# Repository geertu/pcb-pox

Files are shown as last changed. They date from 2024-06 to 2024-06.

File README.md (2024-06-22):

# POX - Power-Opto Extension Board (KiCad PCB)

This is a small extension board to control operation of two development boards,
e.g. on your desk, or in a board farm.  It is mainly intended for use with
BCU/2 (https://github.com/geertu/pcb-bcu2), but it can be used with any
microcontroller or single-board computer that has a compatible I2C interface.

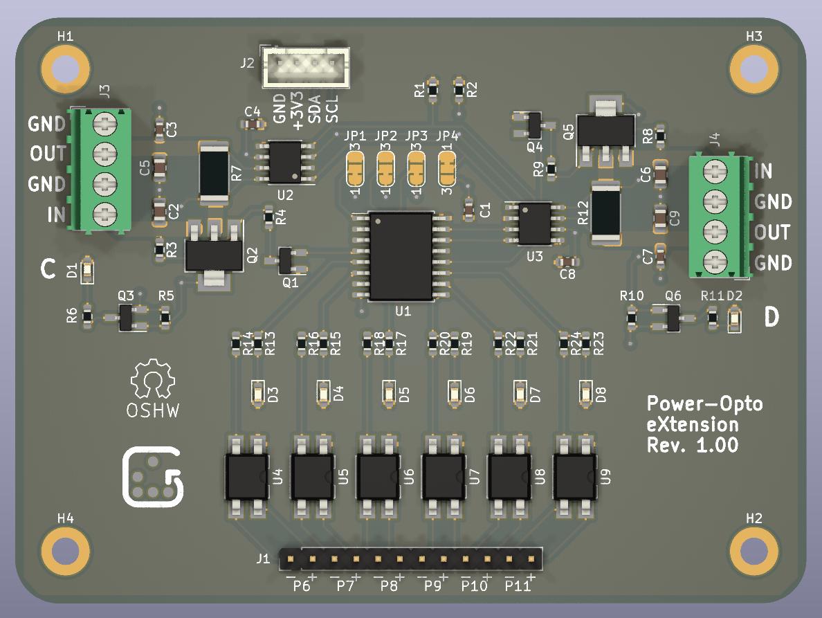
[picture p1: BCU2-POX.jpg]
PCB


## Features

  - Controlled over I2C,
  - Two power control and measurement channels (3.3-14V, max. 3.2A),
  - Six opto-isolators for e.g. reset, wake-up, and keypress simulation.

## Software

Software to run on BCU/2+POX is available from
https://github.com/geertu/teensy3-bcu2/tree/bcu2%2Bpox in source form.

## License

CC-BY-SA-4.0 (https://creativecommons.org/licenses/by-sa/4.0/)

## PCB and Parts

PCB and parts can be ordered at
https://aisler.net/geert/power-opto-extension/bcu2-pox (Disclaimer: I'm not
affiliated to AISLER). Note that the project at Aisler predates the change from
NTF6P02 to DMP6023LE-13.

## Bill Of Materials

  - C1, C3, C4, C7, C8: Capacitor, 100nF, SMD 0603/1608
  - C2, C5, C6, C9: Capacitor, 10µF, SMD 0805/2012, 25V
  - D1, D2: LED Green clear, SMD 0603/1608
  - D3-D8: LED Yellow clear, SMD 0603/1608
  - J1: Male 1x12 header 2.54mm
  - J2: Male 1x4 header, RM 2mm, e.g. JST B4B-PH-K
  - J3, J4: Screw type, terminal block, RM 3.5mm
  - Q1, Q3, Q4, Q6: MOSFET N-channel 60V 115mA, SOT23-3
  - Q2, Q5: MOSFET P-channel e.g. 60V 7A (DMP6023LE-13) or
				  20V 10A (NTF6P02), SOT223
  - R1, R2: Resistor, 4.7kΩ, SMD 0603/1608 (optional, I2C pull-ups)
  - R3, R8: Resistor, 47kΩ, SMD 0603/1608
  - R4, R9: Resistor, 10kΩ (when using DMP6023LE-13) or
		      47kΩ (when using NTF6P02), SMD 0603/1608
  - R5, R10: Resistor, 100kΩ, SMD 0603/1608
  - R6, R11, R13, R15, R17, R19, R21, R23: Resistor, 1kΩ, SMD 0603/1608
  - R7, R12: Resistor, 100mΩ, SMD 2512/6432, 1%, 2W
  - R14, R16, R18, R20, R22, R24: Resistor, 270Ω, SMD 0603/1608
  - U1: PFC8574, 16-SOIC (wide)
  - U2, U3: INA219xID power monitor, 8-SOIC
  - U4-U9: Opto-isolator, Mini-Flat-4, e.g. Broadcom HCPL-181-00CE

## Connector pinouts

  - J1: Opto-isolator channels 6-11

    Pin               | Function
    ----------------- | --------
     1-11 (odd pins)  | Emitter ("negative output")
     2-12 (even pins) | Collector ("positive output")

  - J2: I2C[A]

    Pin | Function
    --- | --------
     1  | GND
     2  | +3.3V
     3  | SDA
     4  | SCL

  - J3 / J4: Power channels C & D

    Pin | Function
    --- | --------
     1  | GND
     2  | Power OUT
     3  | GND
     4  | Power IN (3.3-14V, max. 3.2A)

## Footnotes

  * [A] Pin order of the I2C connector is similar (but reversed!) to the Seeed
	Studio Grove and SparkFun Qwiic Connect systems, although the connector
	used is different (you can probably mount a real Grove connector
	instead).

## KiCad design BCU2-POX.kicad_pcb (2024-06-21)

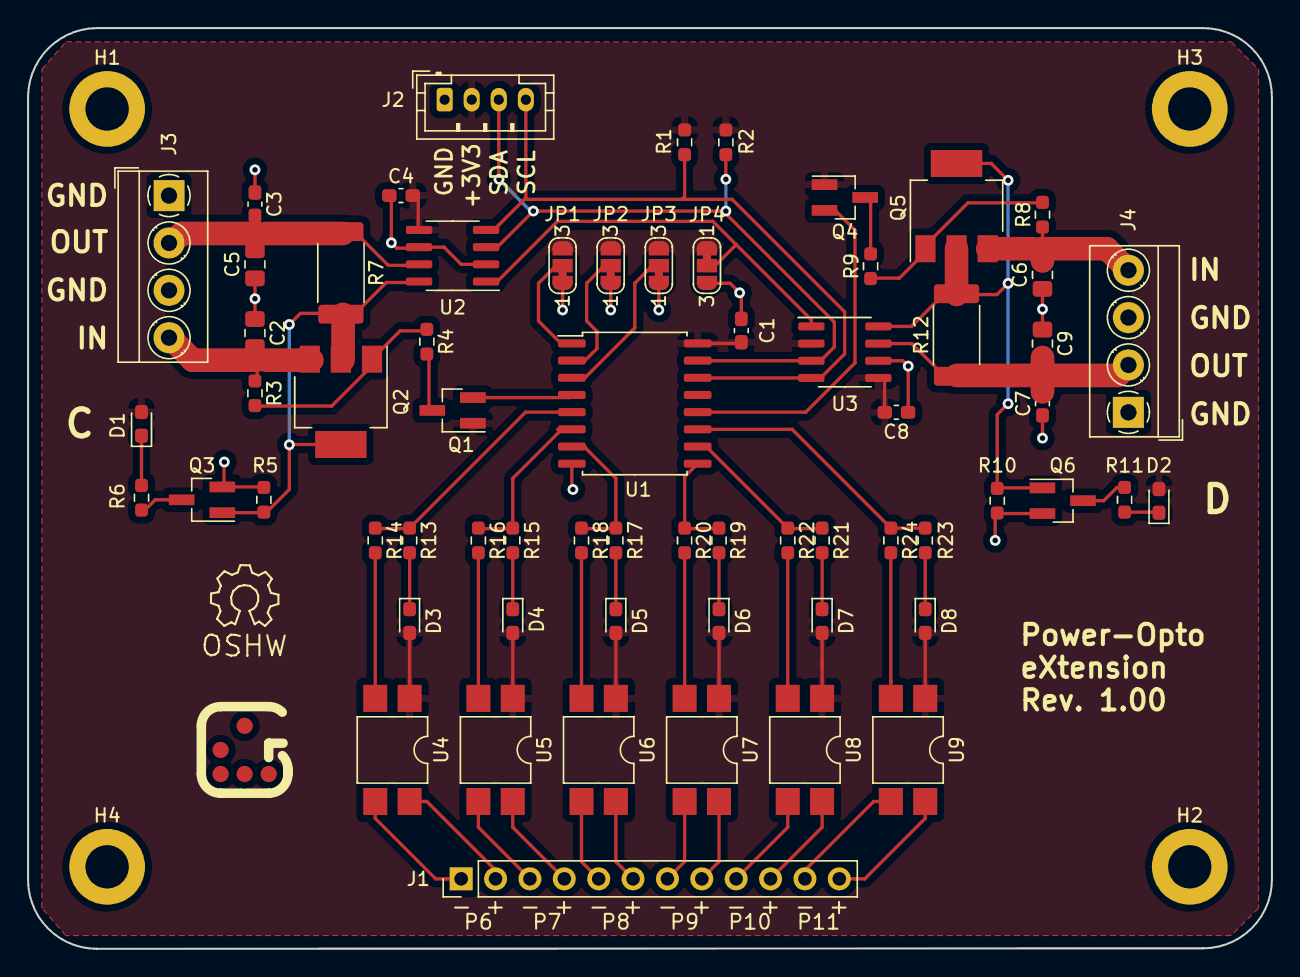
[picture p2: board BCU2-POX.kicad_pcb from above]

Board: 2 copper layers, 91.9 x 68.0 mm, 70 parts (0 on the bottom side), 54 nets.

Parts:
C1, C3, C4, C7, C8: 100n; C_0603_1608Metric_Pad1.08x0.95mm_HandSolder
C2, C5, C6, C9: 10µ; C_0805_2012Metric_Pad1.18x1.45mm_HandSolder
D1, D2: Green; LED_0603_1608Metric_Pad1.05x0.95mm_HandSolder
D3, D4, D5, D6, D7, D8: Yellow; LED_0603_1608Metric_Pad1.05x0.95mm_HandSolder
Glider: Glider logo; Glider_bvba_G_Medium
H1, H2, H3, H4: MountingHole_Pad; MountingHole_3.2mm_M3_DIN965_Pad
J1: Conn_01x12_Male; PinHeader_1x12_P2.54mm_Vertical
J2: Conn_01x04_Male; JST_PH_B4B-PH-K_1x04_P2.00mm_Vertical
J3, J4: Screw_Terminal_01x04; TerminalBlock_MetzConnect_Type059_RT06304HBWC_1x04_P3.50mm_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
JP1, JP2, JP3, JP4: SolderJumper_3_Bridged12; SolderJumper-3_P1.3mm_Bridged12_RoundedPad1.0x1.5mm_NumberL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
OSHW: Symbol_OSHW-Logo_SilkScreen
Q1, Q3, Q4, Q6: 2N7002; SOT-23_Handsoldering
Q2, Q5: DMP6023LE-13; SOT-223-3_TabPin2
R1, R2: 4K7; R_0603_1608Metric_Pad0.98x0.95mm_HandSolder
R3, R8: 47K; R_0603_1608Metric_Pad0.98x0.95mm_HandSolder
R4, R9: 10K; R_0603_1608Metric_Pad0.98x0.95mm_HandSolder
R5, R10: 100K; R_0603_1608Metric_Pad0.98x0.95mm_HandSolder
R6, R11, R13, R15, R17, R19, R21, R23: 1K; R_0603_1608Metric_Pad0.98x0.95mm_HandSolder
R7, R12: 0.1 1% 2W; R_2512_6332Metric_Pad1.40x3.35mm_HandSolder
R14, R16, R18, R20, R22, R24: 270; R_0603_1608Metric_Pad0.98x0.95mm_HandSolder
U1: PCF8574; SOIC-16W_7.5x10.3mm_P1.27mm
U2, U3: INA219xID; SOIC-8_3.9x4.9mm_P1.27mm
U4, U5, U6, U7, U8, U9: HCPL-181; SMDIP-4_W7.62mm

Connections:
+3V3: C1.1, C4.2, C8.2, D1.2 (A), D2.2 (A), D3.2 (A), D4.2 (A), D5.2 (A), D6.2 (A), D7.2 (A), D8.2 (A), J2.2, JP1.3 (B), JP2.3 (B), JP3.3 (B), JP4.1 (A), Q1.1 (G), Q4.1 (G), R1.1, R2.1, U1.16 (VDD), U2.5 (Vs), U3.2 (A0), U3.5 (Vs), U4.1, U5.1, U6.1, U7.1, U8.1, U9.1
/Power Channel C/A1: JP4.2 (C), U2.1 (A1), U3.1 (A1)
/Power Channel C/IN: C2.2, J3.4, Q2.3 (S), R3.1
/Power Channel C/OUT: C3.2, C5.2, J3.2, R7.1, U2.7 (Vin-)
/Power Channel D/IN: C6.2, J4.4, Q5.3 (S), R8.1
/Power Channel D/OUT: C7.2, C9.2, J4.2, R12.1, U3.7 (Vin-)
GND: C1.2, C2.1, C3.1, C4.1, C5.1, C6.1, C7.1, C8.1, C9.1, H1.1, H2.1, H3.1, H4.1, J2.1, J3.1, J3.3, J4.1, J4.3, JP1.1 (A), JP2.1 (A), JP3.1 (A), JP4.3 (B), Q3.2 (S), Q6.2 (S), R5.2, R10.2, U1.8 (VSS), U2.2 (A0), U2.6 (GND), U3.6 (GND)
unnamed: D1.1 (K), R6.1
unnamed: D2.1 (K), R11.1
unnamed: D3.1 (K), R13.2
unnamed: D4.1 (K), R15.2
unnamed: D5.1 (K), R17.2
unnamed: D6.1 (K), R19.2
unnamed: D7.1 (K), R21.2
unnamed: D8.1 (K), R23.2
unnamed: JP1.2 (C), U1.1 (A0)
unnamed: JP2.2 (C), U1.2 (A1)
unnamed: JP3.2 (C), U1.3 (A2)
unnamed: Q1.3 (D), R4.2
unnamed: Q2.1 (G), R3.2, R4.1
unnamed: Q2.2 (D), Q3.1 (G), R5.1, R7.2, U2.8 (Vin+)
unnamed: Q3.3 (D), R6.2
unnamed: Q4.3 (D), R9.2
unnamed: Q5.1 (G), R8.2, R9.1
unnamed: Q5.2 (D), Q6.1 (G), R10.1, R12.2, U3.8 (Vin+)
unnamed: Q6.3 (D), R11.2
unnamed: R14.2, U4.2
unnamed: R16.2, U5.2
unnamed: R18.2, U6.2
unnamed: R20.2, U7.2
unnamed: R22.2, U8.2
unnamed: R24.2, U9.2
P6: R13.1, R14.1, U1.5 (P1)
P6+: J1.2, U4.4
P6-: J1.1, U4.3
P7: R15.1, R16.1, U1.6 (P2)
P7+: J1.4, U5.4
P7-: J1.3, U5.3
P8: R17.1, R18.1, U1.7 (P3)
P8+: J1.6, U6.4
P8-: J1.5, U6.3
P9: R19.1, R20.1, U1.9 (P4)
P9+: J1.8, U7.4
P9-: J1.7, U7.3
P10: R21.1, R22.1, U1.10 (P5)
P10+: J1.10, U8.4
P10-: J1.9, U8.3
P11: R23.1, R24.1, U1.11 (P6)
P11+: J1.12, U9.4
P11-: J1.11, U9.3
PWRC_EN: Q1.2 (S), U1.4 (P0)
PWRD_EN: Q4.2 (S), U1.12 (P7)
SCL: J2.4, R1.2, U1.14 (SCL), U2.4 (SCL), U3.4 (SCL)
SDA: J2.3, R2.2, U1.15 (SDA), U2.3 (SDA), U3.3 (SDA)

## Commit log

2024-06-21 Update to KiCad 6
    [BCU-2.kicad_pcb, BCU-2.kicad_sch, BCU-2.sch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]
2024-06-21 .gitignore: Update for KiCad 6
2024-06-21 PCB: Tools → Update Footprints from Library in PCB Editor
    [BCU-2.kicad_pcb]
2024-06-21 PCB: Manual fixup of resistor/capacitor/LED 3D models
    [BCU-2.kicad_pcb]
2024-06-21 PCB: Use the existing Phoenix terminal block 3D model
    instead of the non-existing MetzConnect variant.
    [BCU-2.kicad_pcb]
2024-06-21 PCB: Move LED labels D3-D10 to fix silkscreen overlap errors
    [BCU-2.kicad_pcb]
2024-06-21 PCB: Remove unneeded stubs to fix track has unconnected end warnings
    [BCU-2.kicad_pcb]
2024-06-21 PCB: Fix clearance violation errors
    The pads on the INA219xID footprint became slightly larger in KiCad 6.
    Move a track, and refill the GND zone.
    [BCU-2.kicad_pcb]
2024-06-21 PCB: Move two vias to enlarge +3V3 zone
    [BCU-2.kicad_pcb]
2024-06-21 PCB: Connect NTF6P02 pads to drains to fix missing connection errors
    KiCad doesn't know they are connected internally.
    [BCU-2.kicad_pcb]
2024-06-21 Remove the old BCU-2-cache.lib file
    It is a remnant of KiCad V5, and no longer used by KiCad 6.
2024-06-21 Schematic: Remove UART channels
    [BCU-2.kicad_sch, LedChannel.kicad_sch, OptoChannel.kicad_sch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]
2024-06-21 Schematic: Remove LED channels
    [BCU-2.kicad_sch, LedChannel.kicad_sch]
2024-06-21 Schematic: Remove GPIO expansion connector
    [BCU-2.kicad_sch]
2024-06-21 Schematic: Invert Power Channel Enable signal
    [BCU-2.kicad_sch, PowerChannel.kicad_sch]
2024-06-21 Schematic: Replace Teensy 3.2 by PCF8574
    [BCU-2.kicad_sch, PowerChannel.kicad_sch]
2024-06-21 Schematic: Renumber Power and Opto Channels
    Renumber Power Channels to C-D, and Opto Channels to 6-11, to
    avoid ambiguity with the channel numbers on the base BCU/2.
    [BCU-2.kicad_sch]
2024-06-21 Schematic: Annotate symbol references
    Fill in schematic symbol reference designators.
    [BCU-2.kicad_sch, PowerChannel.kicad_sch]
2024-06-21 Schematic: Add missing PWR_FLAG for GND
    As flagged by perform electrical rules check.
    [BCU-2.kicad_sch]
2024-06-21 Schematic: Re-annotate symbol references
    Fill in schematic symbol reference designators, with reset
    existing annotations.
    [BCU-2.kicad_sch, OptoChannel.kicad_sch, PowerChannel.kicad_sch]
2024-06-21 Schematic: Assign missing footprints
    Run footprint assignment tool.
    [BCU-2.kicad_sch]
2024-06-21 Schematic: Include DNP I2C pull-up resistors in BOM/board
    Else there won't be a footprint in the PCB.
    [BCU-2.kicad_sch]
2024-06-21 Schematic: Update footprints
    Update Capacitor, LED, and Resistor footprints to match KiCad 6.
    [BCU-2.kicad_sch, OptoChannel.kicad_sch, PowerChannel.kicad_sch]
2024-06-21 PCB: Mark OSHW and Glider logos for special handling
    The OSHW and Glider logos are not in the schematic, and to be excluded
    from the BOM. Mark them correctly, so they are not deleted by any
    future update of the PCB with changes made to schematic.
    [BCU-2.kicad_pcb]
2024-06-21 PCB: Update layout for schematic changes
    [BCU-2.kicad_pcb]
2024-06-21 PCB: Update size and mounting holes
    [BCU-2.kicad_pcb]
2024-06-21 Schematic: Update title and date
    Power-Opto Extension Board (POX for BCU/2)
    [BCU-2.kicad_sch, PowerChannel.kicad_sch]
2024-06-21 PCB: Update board name on silkscreen
    Power-Opto eXtension Rev. 1.00
    [BCU-2.kicad_pcb]
2024-06-21 Remove the 74LV1T files
    The Power-Opto eXtension does not use 74LV1T.
2024-06-21 Rename from BCU-2 to BCU2-POX
    [BCU2-POX.kicad_pcb, BCU2-POX.kicad_sch]
2024-06-21 Replace NTF6P02 by DMP6023LE-13
    This requires updating the voltage divider providing gate voltage for
    the larger Gate Threshold (and Gate-Source) Voltage.
    [BCU2-POX.kicad_pcb, BCU2-POX.kicad_sch, PowerChannel.kicad_sch]
2024-06-21 Update PCB image
    Replace the BCU/2 PCB image by the proper POX PCB image.
